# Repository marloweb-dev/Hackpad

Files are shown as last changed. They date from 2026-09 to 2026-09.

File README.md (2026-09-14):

# Hackpad
Cutom keypad for the stardance hackpad challenge

My hackpad has 5 keys, a rotary encoder, a led status bar and an oled display. It uses QMK firmware.

## PCB
Here is the pcb I made in Kicad:





## CAD design
At first for this case I attempted to learn fusion but due to time constraints I pivoted to tinkercad in order to finish on time. The case itself is made up of a base and a lid. I forgot to export the fancy pcb with all the components so apologies for that.





## BOM
For this project I used:

* 5x Cherry MX Switches
* 5x DSA Keycaps
* 6x 1N4148 DO-35 Diodes
* 6x SK6812 MINI-E LEDs
* 1x 0.91" 128x32 OLED Display
* 1x EC11 Rotary Encoder
* 1x XIAO RP2040
* 1x Case (2 3d printed parts)

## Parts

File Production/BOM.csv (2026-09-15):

Quantity | Part | Description | Reference Designator(s)
5 | Cherry MX Switch | Mechanical keyboard switch | SW1,SW2,SW3,SW4,SW5
5 | DSA Keycap | Keycap for MX-style switches
6 | 1N4148 DO-35 | Signal diode (switch matrix) | D2,D3,D4,D5,D6,D12
6 | SK6812MINI-E | Addressable RGB LED
1 | SSD1306 OLED Display | 0.91in 128x32 I2C OLED display | U2
1 | EC11 Rotary Encoder | Rotary encoder with push switch | SW6
1 | Seeed XIAO RP2040 | Main microcontroller | U1
2 | 3D Printed Case Part | Base and lid

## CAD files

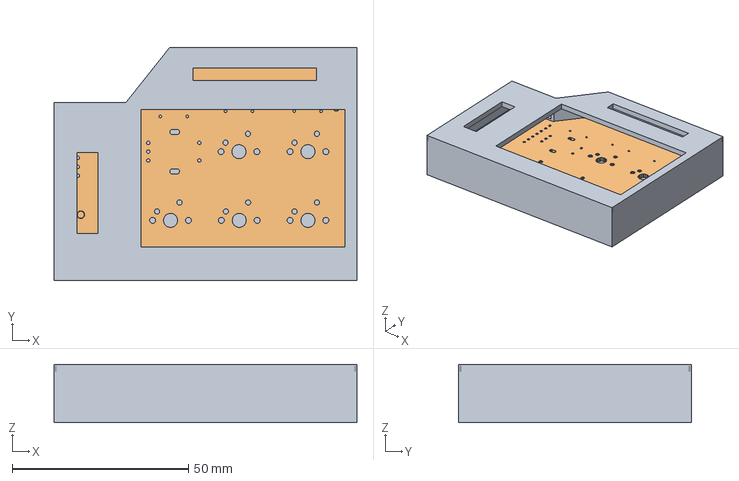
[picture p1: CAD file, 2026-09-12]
CAD/CAD_fully_assembled.step
86.0 x 66.0 x 16.6 mm

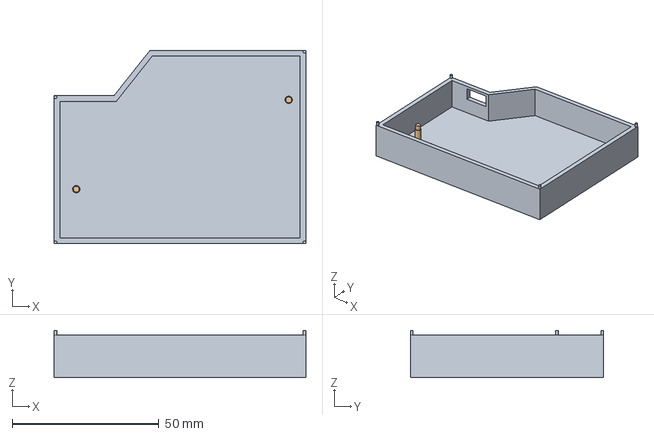
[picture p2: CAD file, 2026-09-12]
Production/Case/CAD_case_base.step
86.0 x 66.0 x 16.1 mm

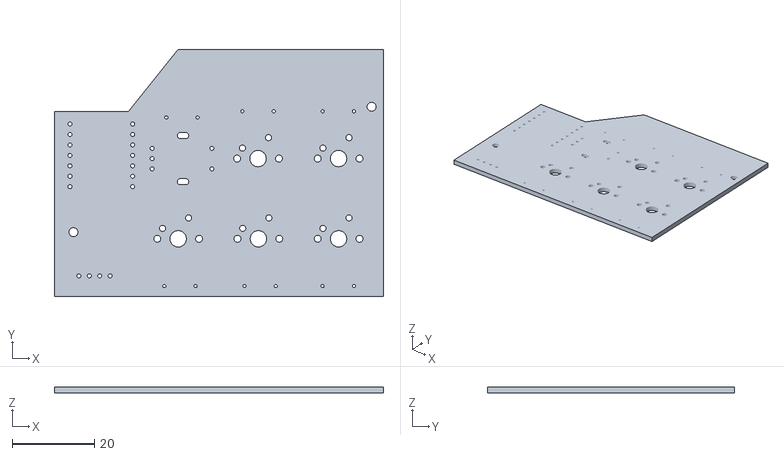
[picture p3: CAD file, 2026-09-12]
CAD/CAD_PCB.stl
80.0 x 60.0 x 1.51

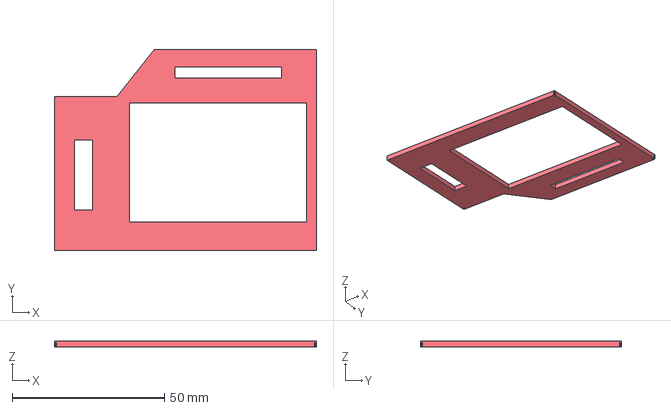
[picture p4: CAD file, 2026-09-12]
Production/Case/CAD_case_lid.step
86.0 x 66.0 x 2.00 mm

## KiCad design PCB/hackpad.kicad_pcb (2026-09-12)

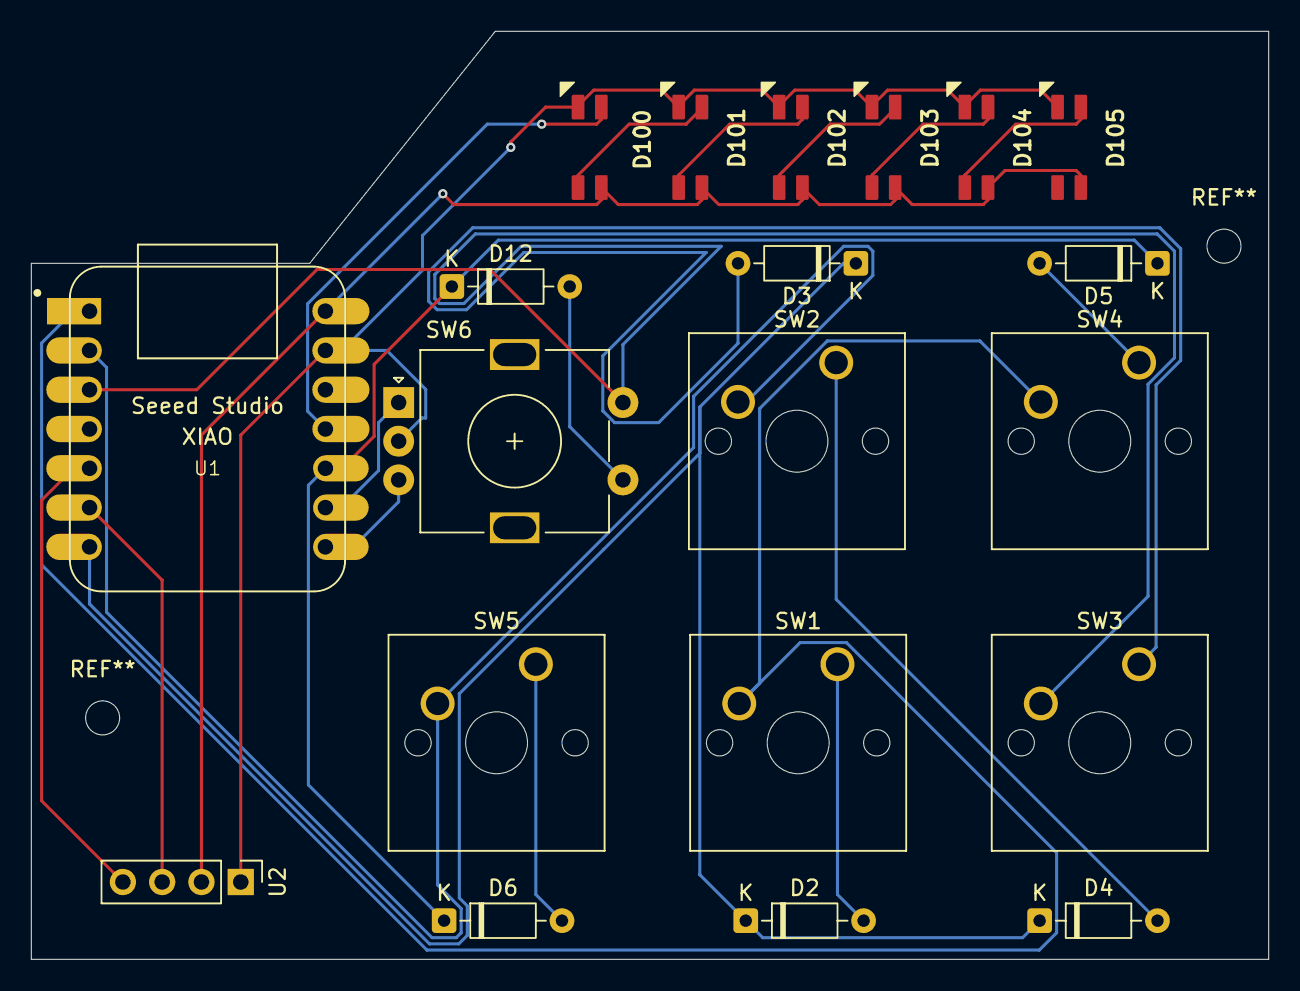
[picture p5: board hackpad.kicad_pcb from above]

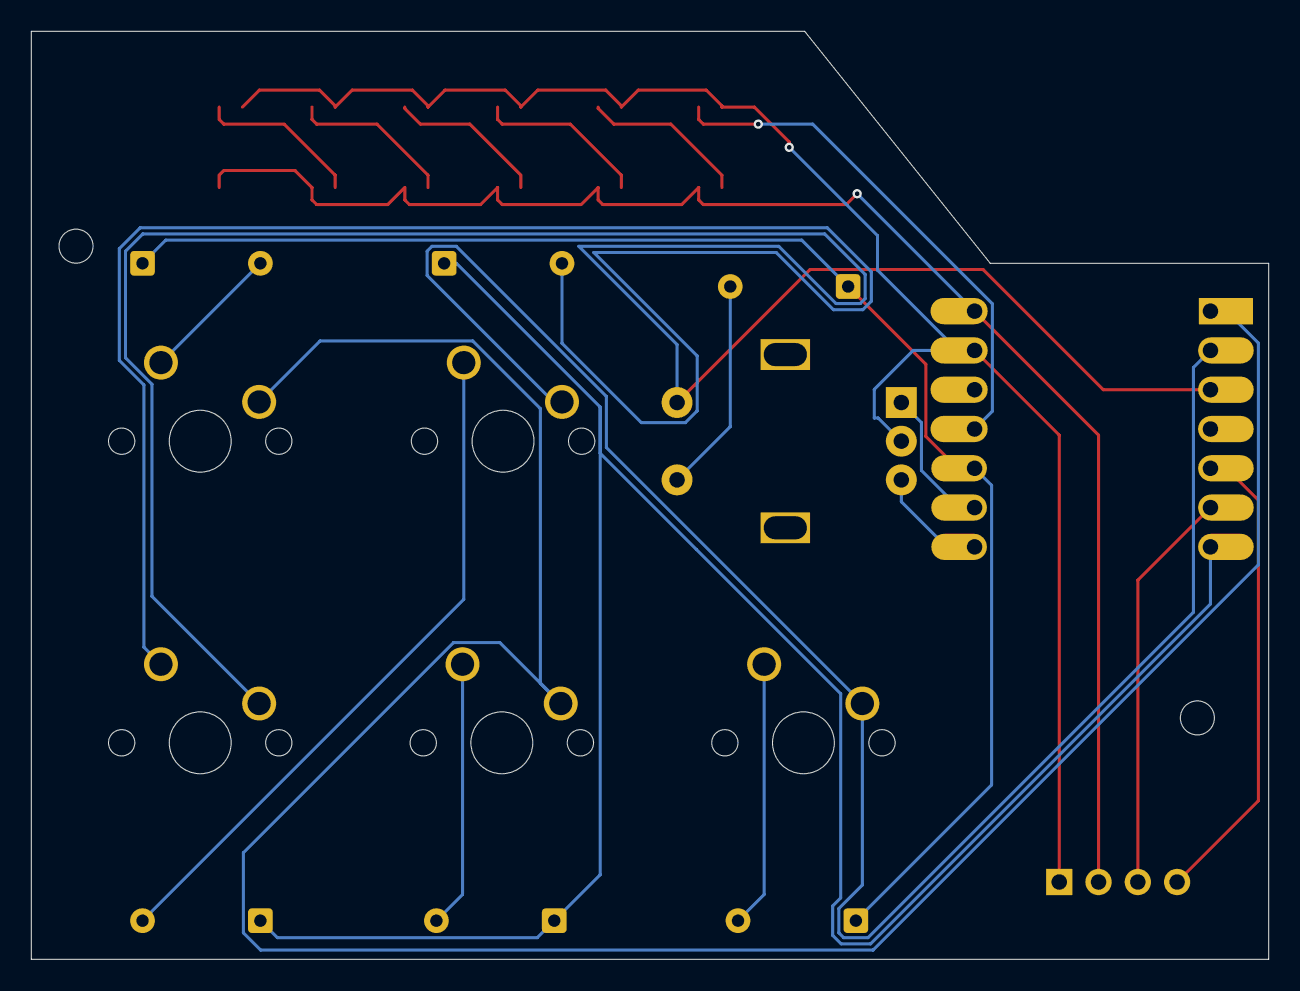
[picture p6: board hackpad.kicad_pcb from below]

Board: 2 copper layers, 80.0 x 60.0 mm, 20 parts (6 on the bottom side), 23 nets.

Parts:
D2, D3, D4, D5, D6, D12: D; D_DO-35_SOD27_P7.62mm_Horizontal
D100, D101, D102, D103, D104, D105: SK6812MINI-E_fixed
SW1, SW2, SW3, SW4, SW5: SW_Push; SW_Cherry_MX_1.00u_PCB
SW6: RotaryEncoder_Switch; RotaryEncoder_Alps_EC11E-Switch_Vertical_H20mm
U1: MOUDLE-SEEEDUINO-XIAO; XIAO-Generic-Hybrid-14P-2.54-21X17.8MM
U2: PinHeader_1x04_P2.54mm_Vertical

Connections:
COL1: SW1.2, SW4.2, U1.1 (PA02_A0_D0)
COL2: SW2.2, SW5.2, U1.2 (PA4_A1_D1)
COL3: SW3.2, SW6.S2, U1.3 (PA10_A2_D2)
GND: D100.3 (VSS), D101.3 (VSS), D102.3 (VSS), D103.3 (VSS), D104.3 (VSS), D105.3 (VSS), SW6.C, U1.13 (GND), U2.1 (GND)
LEDS: D100.4 (DIN), U1.11 (PA6_A10_D10_MOSI)
unnamed: D2.2 (A), SW1.1
unnamed: D3.2 (A), SW3.1
unnamed: D4.2 (A), SW2.1
unnamed: D5.2 (A), SW4.1
unnamed: D6.2 (A), SW5.1
unnamed: D100.2 (DOUT), D101.4 (DIN)
unnamed: D101.2 (DOUT), D102.4 (DIN)
unnamed: D102.2 (DOUT), D103.4 (DIN)
unnamed: D103.2 (DOUT), D104.4 (DIN)
unnamed: D104.2 (DOUT), D105.4 (DIN)
REA: SW6.A, U1.9 (PA7_A8_D8_SCK)
REB: SW6.B, U1.8 (PB09_A7_D7_RX)
RES1: D12.2 (A), SW6.S1
ROW1: D2.1 (K), D3.1 (K), D4.1 (K), U1.7 (PB08_A6_D6_TX)
ROW2: D5.1 (K), D6.1 (K), D12.1 (K), U1.10 (PA5_A9_D9_MISO)
SCL: U1.6 (PA9_A5_D5_SCL), U2.3 (SCL)
SDA: U1.5 (PA8_A4_D4_SDA), U2.4 (SDA)
VCC: D100.1 (VDD), D101.1 (VDD), D102.1 (VDD), D103.1 (VDD), D104.1 (VDD), D105.1 (VDD), U1.14 (5V), U2.2 (VCC)

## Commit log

2026-09-12 Enhance README with project details and images
    Added detailed project description, PCB images, CAD design, and BOM.
2026-09-12 All files pertaining to hackpad
    [CAD_PCB.stl, CAD_case_base.step, CAD_case_lid.step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]
2026-09-12 Fix formatting in keyboard.json for ws2812 pin
2026-09-12 Replace WS2812B LEDs with SK6812 MINI-E LEDs
2026-09-12 Clarify CAD design process in README
    Updated the CAD design section to clarify the transition from Fusion to Tinkercad and provided a more detailed description of the case components.
2026-09-15 Updated BOM
    [BOM.csv]
